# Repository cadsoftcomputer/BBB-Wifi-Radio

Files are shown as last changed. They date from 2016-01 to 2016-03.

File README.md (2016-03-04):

# BBB-Wifi-Radio
Internet Radio based on the Beaglebone Black platform made by Jorge Garcia

This repository contains the hardware and software files I created in order to make a Wifi Radio using the Beaglebone Black
single board computer.

This Radio use a Python-Tkinter interface to communicate with MPC and MPD in order to play internet radio stations. In th
various folders you will find further information about what each of the files contains and what their purpose is in the
scheme of the project.

If you have any questions please feel free to contact me, jorge@cadsoftusa.com or call 954-237-0932.

I would like to extend a special thanks to Shabaz from the Element14 community and Robert C Nelson, William Hermans,
Peter Gregory from the Beagleboard Groups forum, and Dr. Derek Molloy author of Exploring Beaglebone . Without their help and insight this project would never have been completed.

Here are links to the resources used in developing this project, I tried to organize them as best as I could

Inspiration
* http://mightyohm.com/blog/2008/10/building-a-wifi-radio-part-1-introduction/

Setting up MPC and MPD
* http://crunchbang.org/forums/viewtopic.php?pid=182574

Audio Cape Design
* http://www.element14.com/community/community/designcenter/single-board-computers/next-gen_beaglebone/blog/2013/05/28/bbb--audio-notes
* http://www.element14.com/community/community/designcenter/single-board-computers/next-gen_beaglebone/blog/2013/07/06/bbb--building-a-dac

BeagleBoard Forum
* https://groups.google.com/forum/#!forum/beagleboard

Device Tree Overlay Info
* http://derekmolloy.ie/gpios-on-the-beaglebone-black-using-device-tree-overlays/
* http://elinux.org/BeagleBone_and_the_3.8_Kernel
* https://github.com/beagleboard/linux/blob/3.8/firmware/capes/cape-boneblack-hdmi-00A0.dts

Python
* https://www.python.org/
* http://www.diveintopython3.net/

Tkinter References
* http://www.tkdocs.com/
* http://infohost.nmt.edu/tcc/help/pubs/tkinter/web/index.html

LXDE 
* https://wiki.archlinux.org/index.php/LXDE#Autostart_Programs

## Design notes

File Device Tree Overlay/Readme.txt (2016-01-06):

jorge-audio-cape-00A0.dts

This is the device tree overlay file that tells Beaglebone Black what 
peripherals to enable in order for the cape to work.

In this particular case, all this .dts file does is enable HDMI audio
without enabling HDMI video. It's very important that HDMI video
not be enabled since those pins are used by the screen to bring up the 
desktop.

This file needs to be compiled on the Beaglebone and the resulting .dtbo 
file needs to be copied to the /lib/firmware directory.

The full process is described here:
https://learn.adafruit.com/introduction-to-the-beaglebone-black-device-tree/compiling-an-overlay

To enable the cape at startup without an eeprom, add the following lines to uEnv.txt in the /boot directory:
cape_enable=capemgr.enable_partno=jorge-audio-cape

also make sure the following line is uncommented, this disables the default HDMI video and audio:
cape_disable=capemgr.disable_partno=BB-BONELT-HDMI,BB-BONELT-HDMIN

Normally this would be enough, however the latest kernel also requires that you add the following line to /etc/default/capemgr:
CAPE=jorge-audio-cape

This will allow the cape to be automatically loaded at startup.

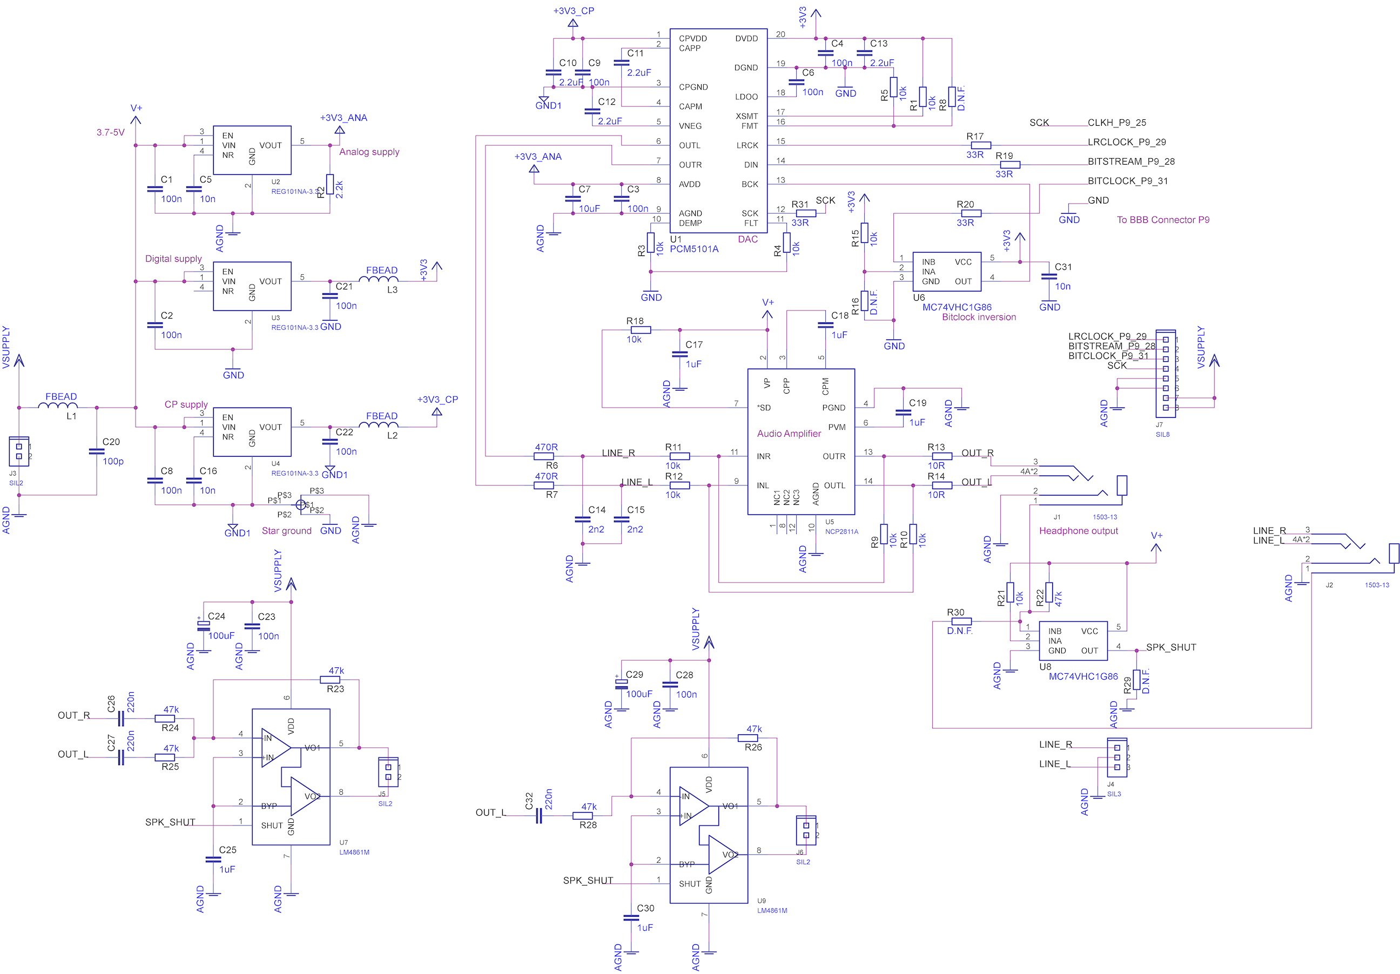
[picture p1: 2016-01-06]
Shabaz_Work/dac-documentation-v1/dac-documentation/dac-schematic1.png

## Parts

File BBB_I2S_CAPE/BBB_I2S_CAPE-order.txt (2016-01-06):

Quantity	Value	Package	Order code	Manufacturer	Manuf. Code	Availability	Price (from)	Description
6	2.2uF	C0805	55Y9834		GCM21BR71C225KA64L	3000	0.061	MURATA - GCM21BR71C225KA64L - CAP, MLCC, X7R, 2.2UF, 16V, 0805
6	0.1uF	C0805	07J8753	VISHAY/VITRAMON	VJ0805Y104KXAMT	3000	0.044	VISHAY VITRAMON - VJ0805Y104KXAMT - CERAMIC CAPACITOR, 0.1UF, 50V, X7R, 0805
3	10uF	C0805	37T9053		08053D106KAT2A	57023	0.213	AVX - 08053D106KAT2A - CAPACITOR CERAMIC, 10UF, 25V, X5R, 10%, SMD
4	2.2nF	C0805	19C6333	AVX CORPORATION	08055C222KAT2A	121553	0.008	AVX - 08055C222KAT2A - CERAMIC CAPACITOR 2200PF, 50V, X7R, 10%, 0805
6	470pF	C0805	06R3855		MC0805B471K500CT	4765	0.005	MULTICOMP - MC0805B471K500CT - CERAMIC CAPACITOR, 470PF, 50V, X7R, 10%, 0805
10	1uF	C0805	47Y9746		C0805X105K3RACAUTO	2330	0.26	KEMET - C0805X105K3RACAUTO - CAP, MLCC, X7R, 1UF, 25V, 0805
3	10n	C0805	06R3733		MC0805B103K500CT	1961	0.005	MULTICOMP - MC0805B103K500CT - CERAMIC CAPACITOR 0.01UF, 50V, X7R, 10%, 0805
3	35RAPC4BHN2	35RAPC4BHN2	96F9607	SWITCHCRAFT	35RAPC4BHN2	771	0.645	SWITCHCRAFT - 35RAPC4BHN2 - CONNECTOR, RCA/PHONO, JACK, 3 POSITION
3	PCM5102A	TSSOP20	49X0828		PCM5102AQPWRQ1	694	3.21	TEXAS INSTRUMENTS - PCM5102AQPWRQ1 - AUDIO STEREO DAC, 32BIT, TSSOP-20
6	TC1015	SOT23-5L	34M8764		TC1015-3.3VCT713	3191	0.294	MICROCHIP - TC1015-3.3VCT713 - IC, V REG, LDO 100MA, SMD, SOT-23-5
3	MC74VHC1G86	SOT23-5L	10C2398	TEXAS INSTRUMENTS	SN74AHC1G86DBVR	1769	0.1	TEXAS INSTRUMENTS - SN74AHC1G86DBVR - SINGLE XOR GATE, 2I/P, SOT-23-5
6	0.68uH	R0805	10R8691		MCFT000156	11820	0.174	MULTICOMP - MCFT000156 - INDUCTOR, FERRITE, 0805, 0.68UH
8	10k	R0805	01N7380		MCTC0525B1002T5E	48675	0.117	MULTICOMP - MCTC0525B1002T5E - THIN FILM RESISTOR, 10KOHM, 100mW, 0.1%
8	33	R0805	06X5177		CR0805-JW-330ELF	24840	0.01	BOURNS - CR0805-JW-330ELF - Surface Mount Thick Film Resistor, CR Series, 33 ohm, 125 mW, -  5%, 150 V, 0805 [2012 Metric] 
4	470	R0805	08N2174		ERA-6AEB471V	3329	0.033	PANASONIC ELECTRONIC COMPONENTS - ERA-6AEB471V - METAL FILM RESISTOR, 470 OHM, 125mW, 0.1%

Order list for C:/Users/Jorge/Documents/eagle/BBB Wifi Radio/BBB_I2S_CAPE/BBB_I2S_CAPE.sch								
Exported from EAGLE with DesignLink

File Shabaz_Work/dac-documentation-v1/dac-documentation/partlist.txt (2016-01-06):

DAC Board parts list

D.N.F. means Do Not Fit

Part     Value          Device   
----     ------------   ------------------------------             

C1       100n           Capacitor 0603  SMD              
C2       100n           Capacitor 0603  SMD              
C3       100n           Capacitor 0603  SMD              
C4       100n           Capacitor 0603  SMD              
C5       10n            Capacitor 0603  SMD              
C6       100n           Capacitor 0603  SMD              
C7       10uF           Capacitor 0805 X5R  SMD              
C8       100n           Capacitor 0603  SMD              
C9       100n           Capacitor 0603  SMD              
C10      2.2uF          Capacitor 0805  SMD              
C11      2.2uF          Capacitor 0805  SMD              
C12      2.2uF          Capacitor 0805  SMD              
C13      2.2uF          Capacitor 0805  SMD              
C14      2n2            Capacitor 0603 NP0  SMD              
C15      2n2            Capacitor 0603 NP0  SMD              
C16      10n            Capacitor 0603  SMD              
C17      1uF            Capacitor 0805 X5R SMD              
C18      1uF            Capacitor 0805 X5R SMD              
C19      1uF            Capacitor 0805 X5R SMD              
C20      100p           Capacitor 0603  SMD              
C21      100n           Capacitor 0603  SMD              
C22      100n           Capacitor 0603  SMD              
C23      100n           Capacitor 0603  SMD              
C24      100uF 16V      CAP-PANA-F EEEFP1C101AP Farnell 1539476       
C25      1uF            Capacitor 0805 X5R SMD              
C26      220n           Capacitor 0805  SMD              
C27      220n           Capacitor 0805  SMD              
C28      100n           Capacitor 0603  SMD              
C29      100uF 16V      CAP-PANA-F EEEFP1C101AP Farnell 1539476        
C30      1uF            Capacitor 0805 X5R SMD              
C31      10n            Capacitor 0603  SMD              
C32      220n           Capacitor 0805  SMD              
J1       3.5mm Jack     Lumberg 1503-13 Farnell 1368640            
J2       3.5mm Jack     Lumberg 1503-13 Farnell 1368640            
J3       SIL2           Header 2-way                 
J4       SIL3           Header 3-way                 
J5       SIL2           Header 2-way                 
J6       SIL2           Header 2-way                 
J7       SIL8           Header 8-way                            
L1       FBEAD          0805 Ferrite 2508053017Y0 Farnell 1611983       
L2       FBEAD          0805 Ferrite 2508053017Y0 Farnell 1611983        
L3       FBEAD          0805 Ferrite 2508053017Y0 Farnell 1611983         
R1       10k            Resistor 0603 SMD              
R2       2.2k           Resistor 0603 SMD              
R3       10k            Resistor 0603 SMD              
R4       10k            Resistor 0603 SMD              
R5       10k            Resistor 0603 SMD              
R6       470R           Resistor 0603 SMD              
R7       470R           Resistor 0603 SMD              
R8       D.N.F.         Resistor 0603 SMD              
R9       10k            Resistor 0603 SMD              
R10      10k            Resistor 0603 SMD              
R11      10k            Resistor 0603 SMD              
R12      10k            Resistor 0603 SMD              
R13      10R            Resistor 0603 SMD              
R14      10R            Resistor 0603 SMD              
R15      10k            Resistor 0603 SMD              
R16      D.N.F.         Resistor 0603 SMD              
R17      33R            Resistor 0603 SMD              
R18      10k            Resistor 0603 SMD              
R19      33R            Resistor 0603 SMD              
R20      33R            Resistor 0603 SMD              
R21      10k            Resistor 0603 SMD              
R22      47k            Resistor 0603 SMD              
R23      47k            Resistor 0603 SMD              
R24      47k            Resistor 0603 SMD              
R25      47k            Resistor 0603 SMD              
R26      47k            Resistor 0603 SMD              
R28      47k            Resistor 0603 SMD              
R29      D.N.F.         Resistor 0603 SMD              
R30      D.N.F.         Resistor 0603 SMD              
R31      33R            Resistor 0603 SMD              
U1       PCM5102       PCM5102   TSSOP20 TI         
U2       REG101NA-3.3   REG101 3.3V SOT23-5            
U3       REG101NA-3.3   REG101 3.3V SOT23-5            
U4       REG101NA-3.3   REG101 3.3V SOT23-5            
U5       NCP2811A       NCP2811A   'A' SUFFIX ON SEMI     
U6       MC74VHC1G86    XOR GATE TSOP-5        
U7       LM4861M        LM4861M    SOIC-8 AMP TI 
U8       MC74VHC1G86    XOR GATE TSOP-5        
U9       LM4861M        LM4861M    SOIC-8 AMP TI

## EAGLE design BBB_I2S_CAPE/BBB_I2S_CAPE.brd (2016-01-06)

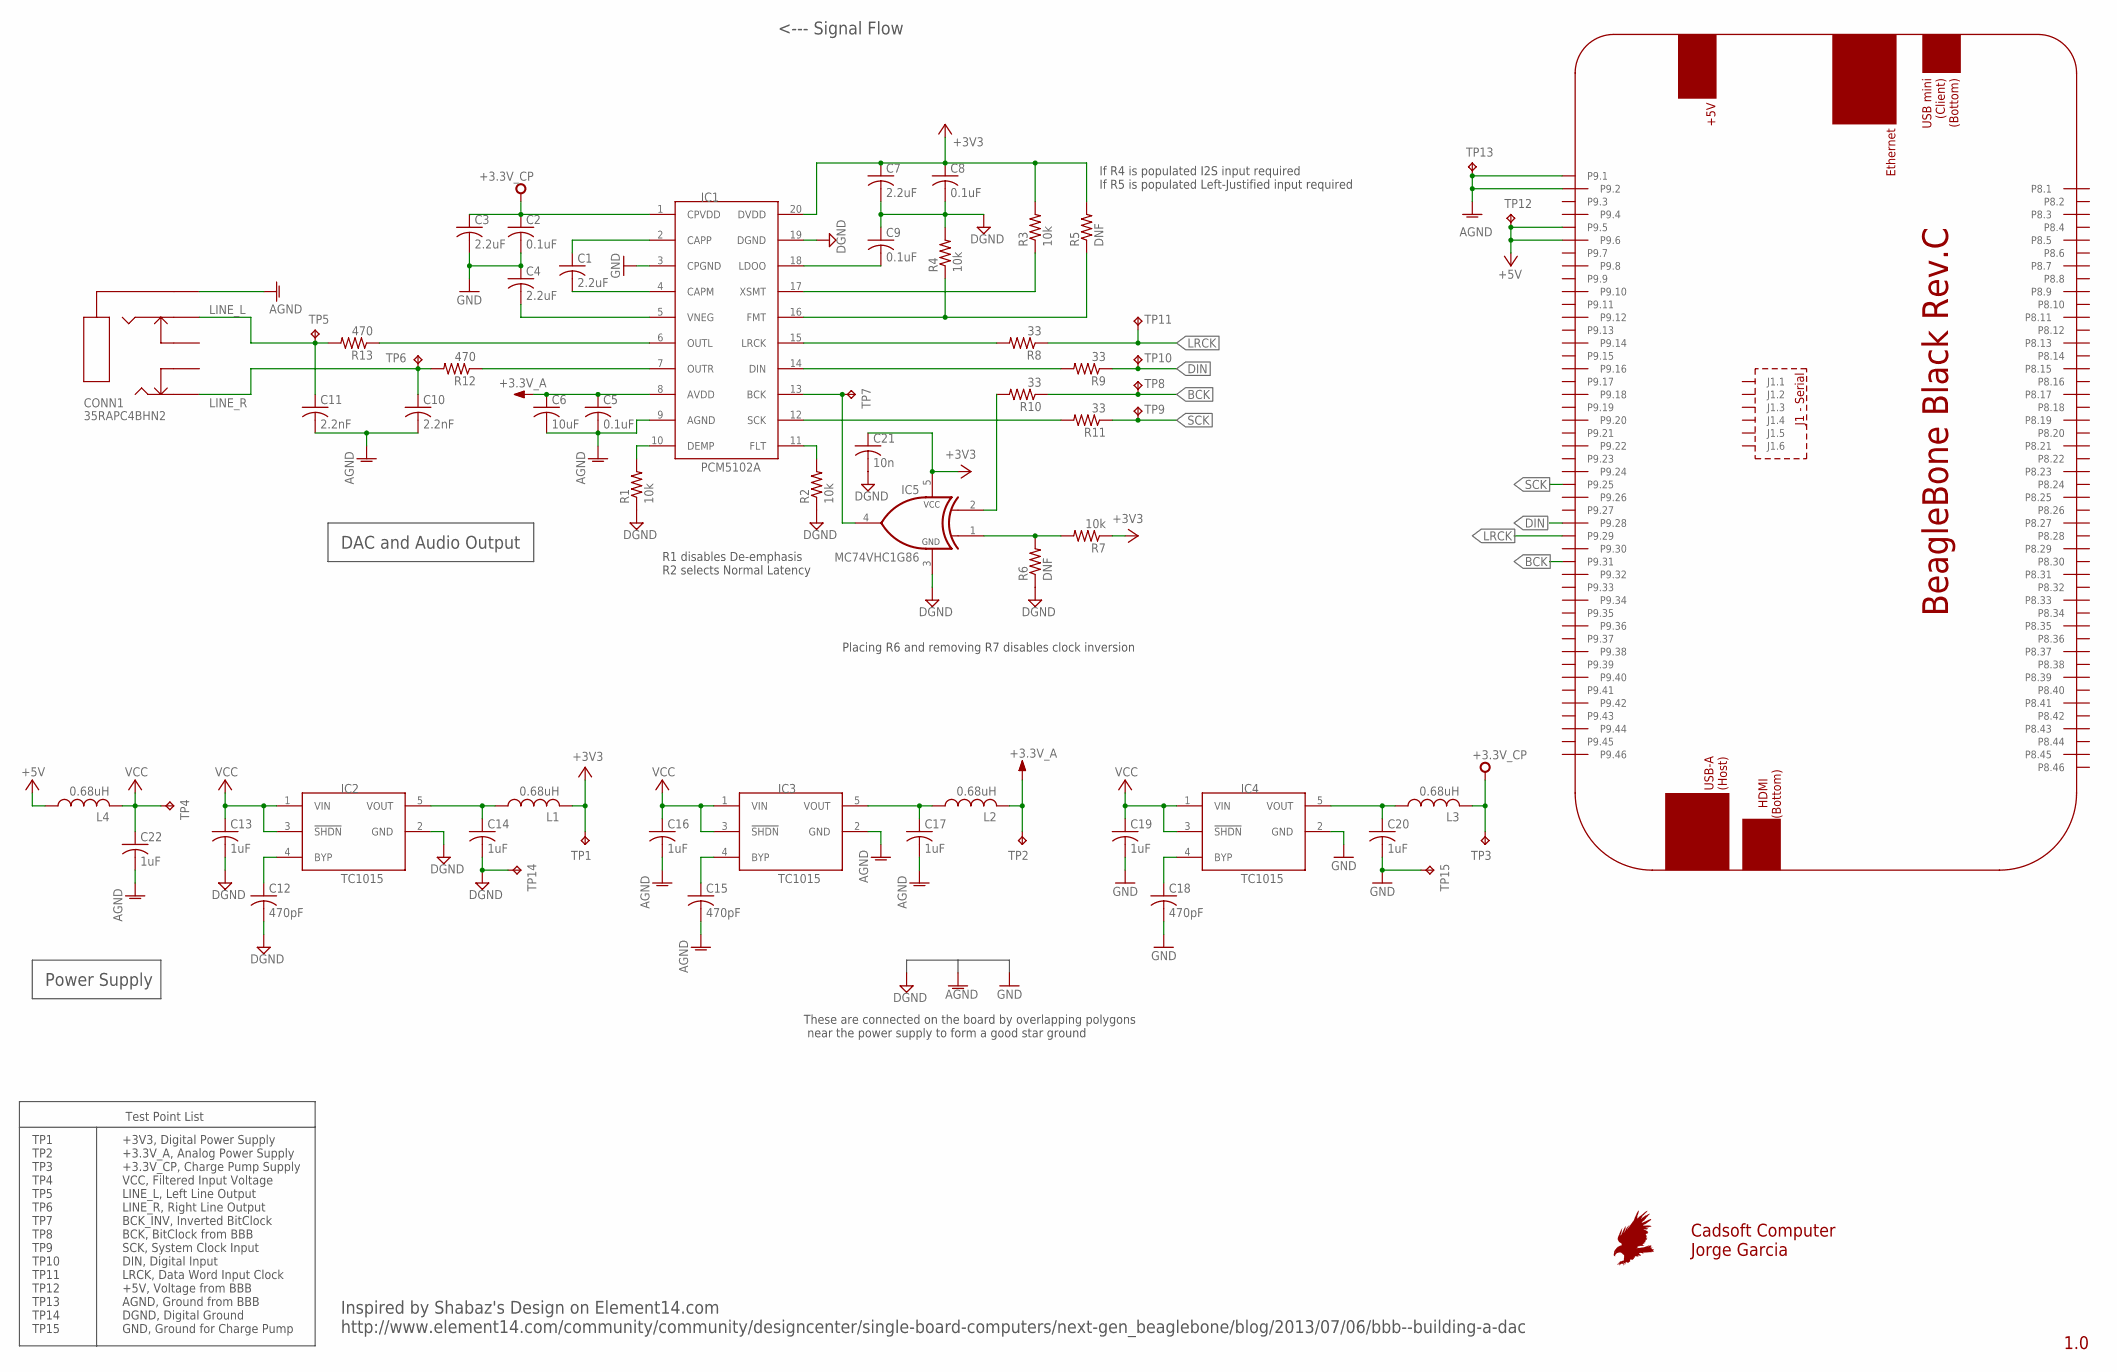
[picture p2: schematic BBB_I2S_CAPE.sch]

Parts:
C1, C3, C4, C7: 2.2uF; C0805; MPN GCM21BR71C225KA64L
C2, C5, C8, C9: 0.1uF; C0805; MPN VJ0805Y104KXAMT
C6: 10uF; C0805; MPN 08053D106KAT2A
C10, C11: 2.2nF; C0805; MPN 08055C222KAT2A
C12, C15, C18: 470pF; C0805; MPN MC0805B471K500CT
C13, C14, C16, C17, C19, C20, C22: 1uF; C0805; MPN C0805X105K3RACAUTO
C21: 10n; C0805; MPN MC0805B103K500CT
CONN1: 35RAPC4BHN2; MPN 35RAPC4BHN2
IC1: PCM5102A; TSSOP20; MPN PCM5102AQPWRQ1
IC2, IC3, IC4: TC1015; SOT23-5L; MPN TC1015-3.3VCT713
IC5: MC74VHC1G86; SOT23-5L; MPN SN74AHC1G86DBVR
L1, L2, L3, L4: 0.68uH; R0805; MPN MCFT000156
PCB1: BEAGLEBONE_BLACK_CAPE
R1, R2, R3, R4, R7: 10k; R0805; MPN MCTC0525B1002T5E
R5, R6: DNF; R0805
R8, R9, R10, R11: 33; R0805; MPN CR0805-JW-330ELF
R12, R13: 470; R0805; MPN ERA-6AEB471V
TP1, TP2, TP3, TP4, TP5, TP6, TP7, TP8, TP9, TP10, TP11, TP12, TP13, TP14, TP15: TPPAD1-17; P1-17

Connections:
+3.3V_A: C5.1, C6.1, IC1.8 (AVDD), L2.2, TP2.TP
+3.3V_CP: C2.1, C3.1, IC1.1 (CPVDD), L3.2, TP3.TP
+3V3: C7.1, C8.1, C21.1, IC1.20 (DVDD), IC5.5 (VCC), L1.2, R3.2, R5.2, R7.1, TP1.TP
+5V: L4.1, PCB1.P9.5, PCB1.P9.6, TP12.TP
AGND: C5.2, C6.2, C10.2, C11.2, C15.2, C16.2, C17.2, C22.2, CONN1.1, IC1.9 (AGND), IC3.2 (GND), PCB1.P9.1, PCB1.P9.2, TP13.TP
BCK: PCB1.P9.31, R10.1, TP8.TP
BCK_INV: IC1.13 (BCK), IC5.4 (OUT), TP7.TP
DGND: C7.2, C8.2, C9.1, C12.2, C13.2, C14.2, C21.2, IC1.19 (DGND), IC2.2 (GND), IC5.3 (GND), R1.1, R2.1, R4.2, R6.1, TP14.TP
DIN: PCB1.P9.28, R9.1, TP10.TP
GND: C2.2, C3.2, C4.1, C18.2, C19.2, C20.2, IC1.3 (CPGND), IC4.2 (GND), TP15.TP
LINE_L: C11.1, CONN1.3, R13.2, TP5.TP
LINE_R: C10.1, CONN1.2, R12.2, TP6.TP
LRCK: PCB1.P9.29, R8.1, TP11.TP
unnamed: C1.2, IC1.4 (CAPM)
unnamed: C1.1, IC1.2 (CAPP)
unnamed: C4.2, IC1.5 (VNEG)
unnamed: IC1.15 (LRCK), R8.2
unnamed: IC1.17 (XSMT), R3.1
unnamed: IC1.14 (DIN), R9.2
unnamed: IC1.10 (DEMP), R1.2
unnamed: IC1.11 (FLT), R2.2
unnamed: IC5.2 (INA), R10.2
unnamed: C9.2, IC1.18 (LDOO)
unnamed: IC5.1 (INB), R6.2, R7.2
unnamed: IC1.16 (FMT), R4.1, R5.1
unnamed: IC1.12 (SCK), R11.2
unnamed: IC1.7 (OUTR), R12.1
unnamed: IC1.6 (OUTL), R13.1
unnamed: C12.1, IC2.4 (BYP)
unnamed: C14.1, IC2.5 (VOUT), L1.1
unnamed: C15.1, IC3.4 (BYP)
unnamed: C17.1, IC3.5 (VOUT), L2.1
unnamed: C18.1, IC4.4 (BYP)
unnamed: C20.1, IC4.5 (VOUT), L3.1
SCK: PCB1.P9.25, R11.1, TP9.TP
VCC: C13.1, C16.1, C19.1, C22.1, IC2.1 (VIN), IC2.3 (!SHDN), IC3.1 (VIN), IC3.3 (!SHDN), IC4.1 (VIN), IC4.3 (!SHDN), L4.2, TP4.TP

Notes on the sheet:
Placing R6 and removing R7 disables clock inversion
If R4 is populated I2S input required If R5 is populated Left-Justified input required
R1 disables De-emphasis R2 selects Normal Latency
<--- Signal Flow
DAC and Audio Output
Power Supply
These are connected on the board by overlapping polygons near the power supply to form a good star ground
TP1 TP2 TP3 TP4 TP5 TP6 TP7 TP8 TP9 TP10 TP11 TP12 TP13 TP14 TP15
+3V3, Digital Power Supply +3.3V_A, Analog Power Supply +3.3V_CP, Charge Pump Supply VCC, Filtered Input Voltage LINE_L, Left Line Output LINE_R, Right Line Output BCK_INV, Inverted BitClock BCK, BitClock from BBB SCK, System Clock Input DIN, Digital Input LRCK, Data Word Input Clock +5V, Voltage f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
Test Point List
1.0
Cadsoft Computer Jorge Garcia
Inspired by Shabaz's Design on Element14.com http://www.element14.com/community/community/designcenter/single-board-computers/next-gen_beaglebone/blog/2013/07/06/bbb--building-a-dac

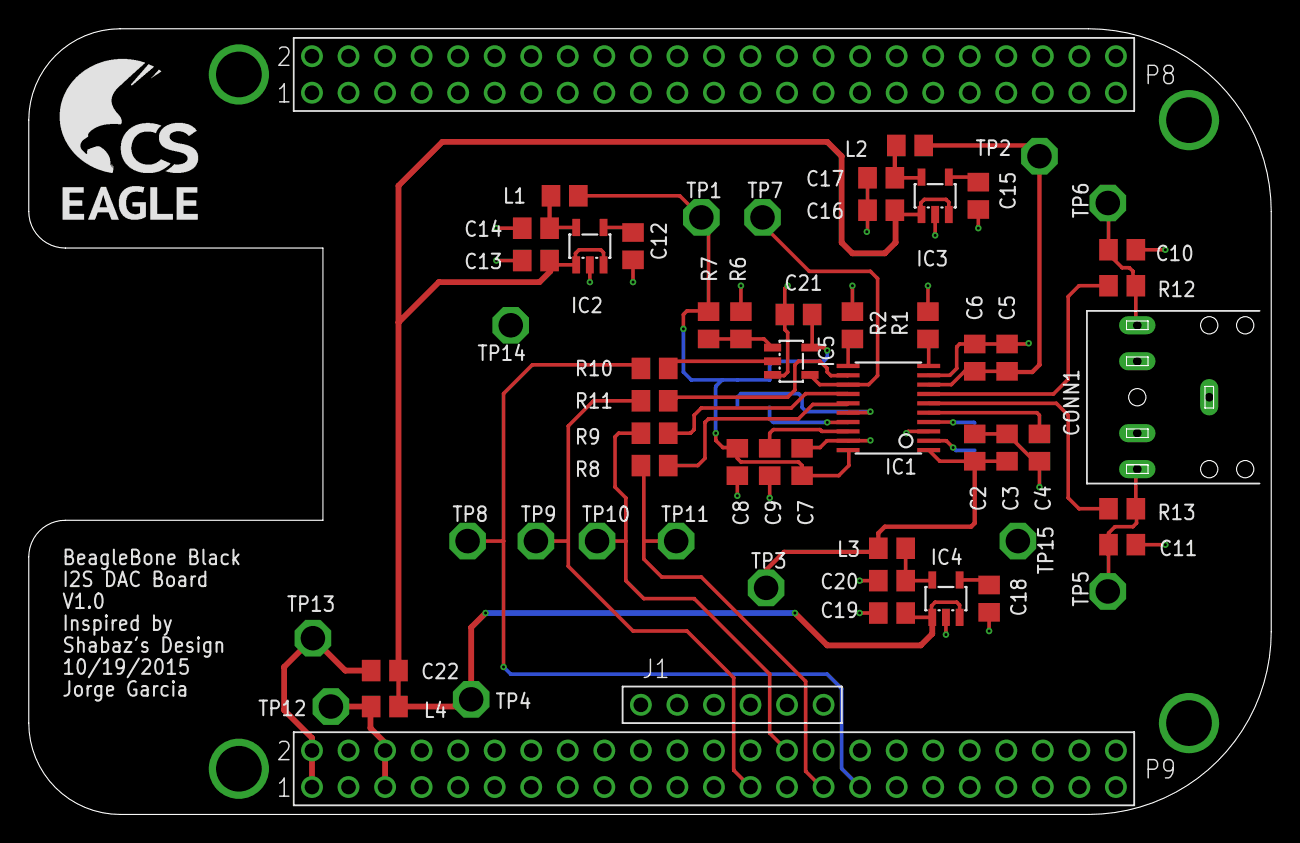
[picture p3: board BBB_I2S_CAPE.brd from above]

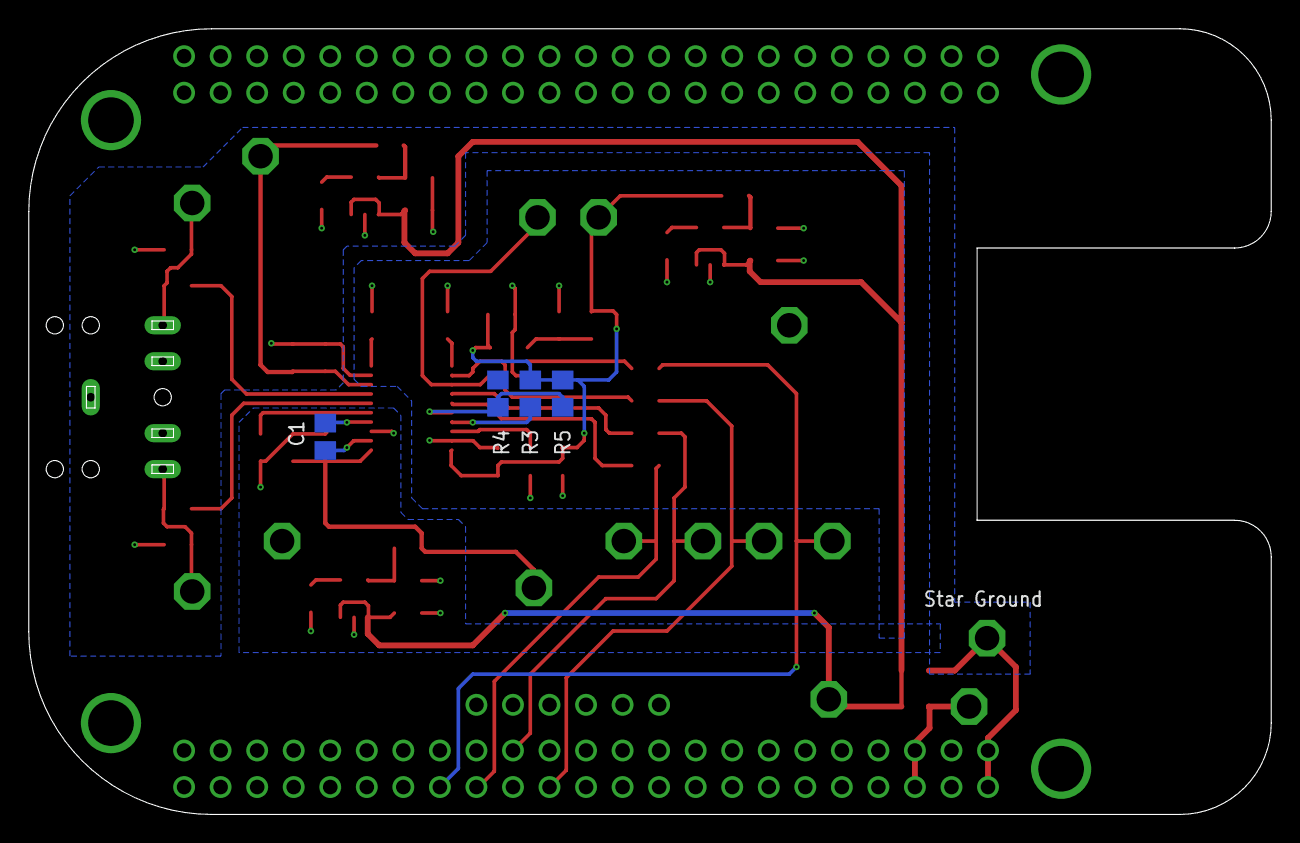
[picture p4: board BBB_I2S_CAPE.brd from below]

Board: 2 copper layers, 86.4 x 54.6 mm, 61 parts (4 on the bottom side), 36 nets.

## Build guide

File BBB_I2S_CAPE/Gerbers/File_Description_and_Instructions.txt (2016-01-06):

Description of Gerber Files

cmp- Top Copper
crc- Top Stencil Mask (Probably not necessary since I'm doing the assembly)
crs- Bottom Stencil Mask (Probably not necessary since I'm doing the assembly)
drd- Excellon Drill file
mil- Milling information. This design uses a part that requires slots instead of normal
     holes. This file contains the location and geometry of those slots.
plc- Top Silkscreen
pls- Bottom Silkscreen
sol- Bottom Copper
stc- Top stop mask
sts- Bottom stop mask

Additional Instructions
- Green or Red stopmask
- White Silkscreen
- HAL process is sufficient
